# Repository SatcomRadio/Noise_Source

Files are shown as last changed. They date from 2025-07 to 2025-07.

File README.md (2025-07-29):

# Noise source board

This repo consists of a board for making a noise source. 

## Warning! This board is still a work in progress!

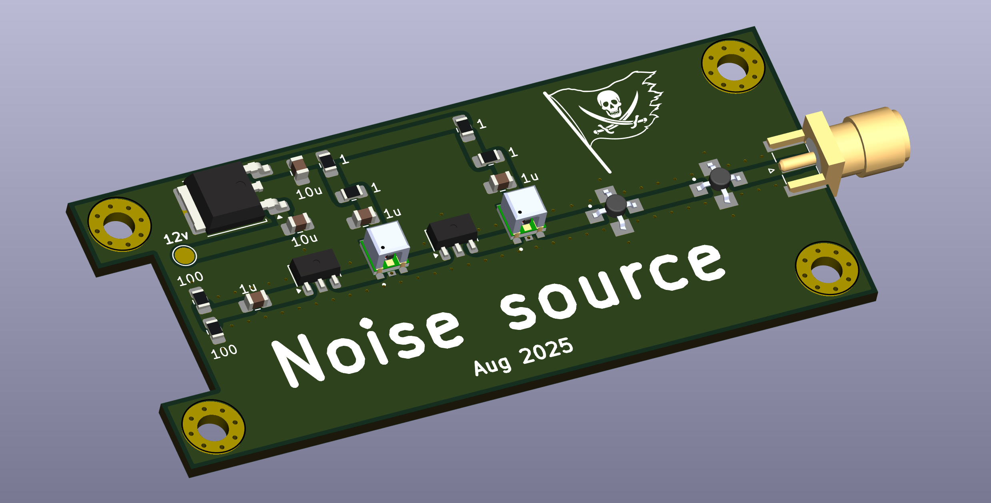
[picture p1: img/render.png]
render


It's based on the one made by [Changpuak](https://www.changpuak.ch/electronics/Noise-Source-with-2xGVA82-15dB.php).

It's adapted to work in a enclosure like [this one](https://www.aliexpress.com/item/1005001849603652.html) of size 92x38x31mm to store it.

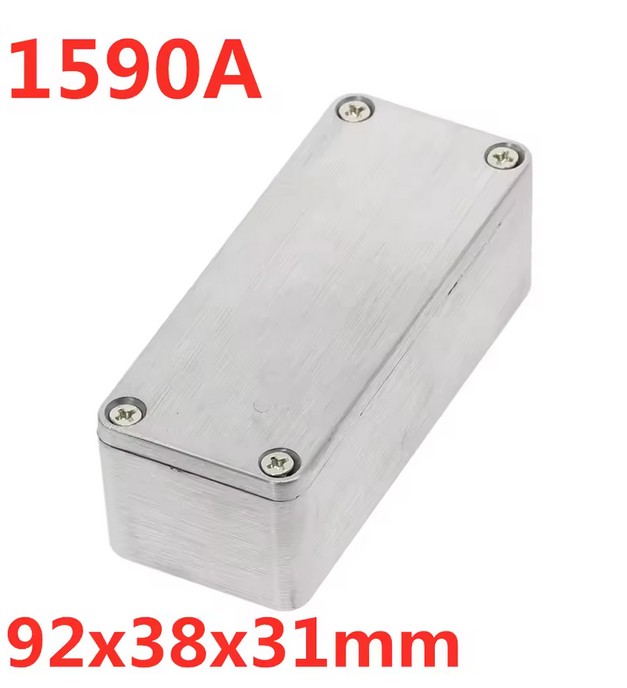
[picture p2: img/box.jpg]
box


------------------------

## Bill of materials

```
4x 0805 1 ohm resistor (https://aliexpress.com/item/1005009264768923.html)
2x 0805 100 ohm resistor (https://aliexpress.com/item/1005009264768923.html)
3x 0805 1uF capacitor (https://aliexpress.com/item/1005005000107445.html)
2x 0805 10uF capacitor (https://aliexpress.com/item/1005005000107445.html)
2x GVA-82+ Mini-Circuits Amplifier (https://aliexpress.com/item/1005008544947091.html)
2x TCBT-14+ Mini-Circuits Bias Tee (https://aliexpress.com/item/1005007678313474.html)
2x PAT-3+ Mini-Circuits 3 dB Attenuator (https://aliexpress.com/item/1005008375039512.html)
1x SMA PCB 1.6mm long connector (https://aliexpress.com/item/1005007424915378.html)
1x 12V barrel jack connector (https://aliexpress.com/item/1005008726787916.html)
1x MC7805CDTG 5v voltage regulator (https://aliexpress.com/item/1005007905517148.html)
1x Storage box (https://www.aliexpress.com/item/1005001849603652.html)
```

------------------------

Schema:

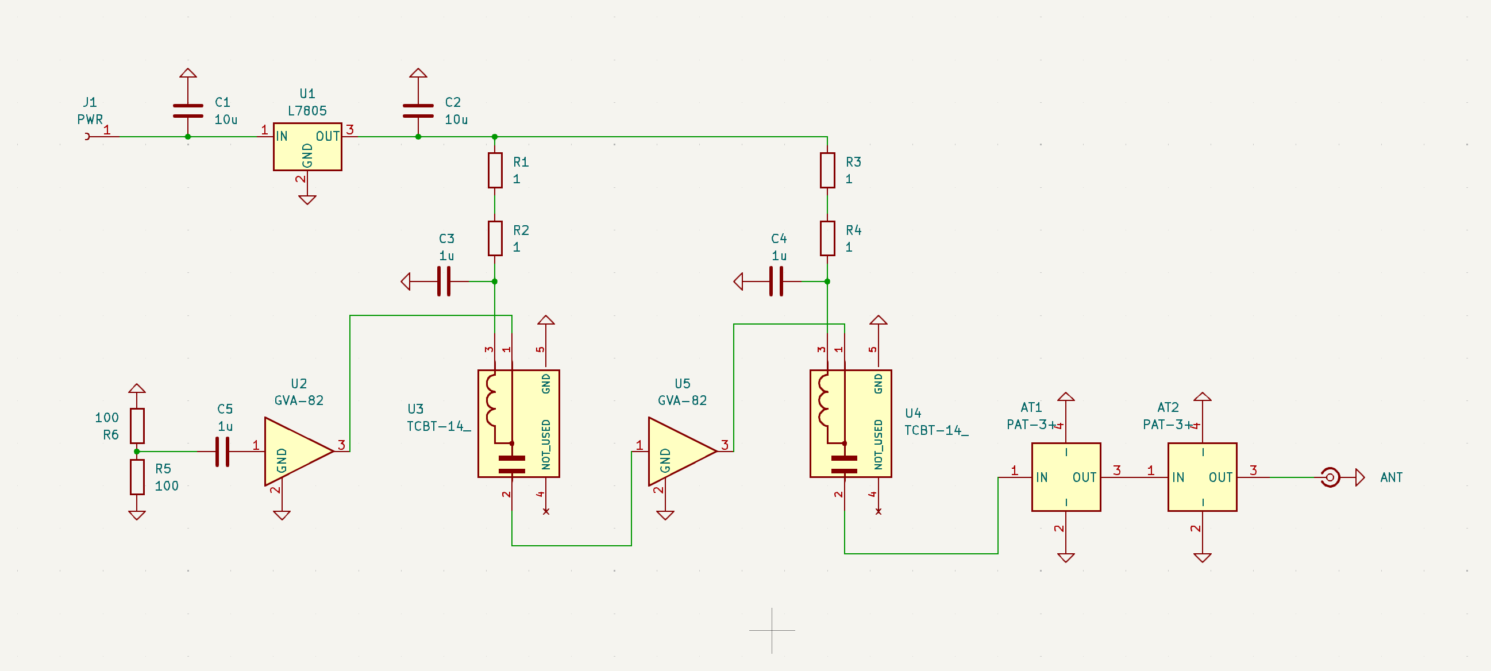
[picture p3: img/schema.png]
schema


------------------------

## Ordering the PCB:

Download the Gerber file from this repo and order it a jlcpcb with the default options.  
The only option I've changed is to remove the manufacture code mark

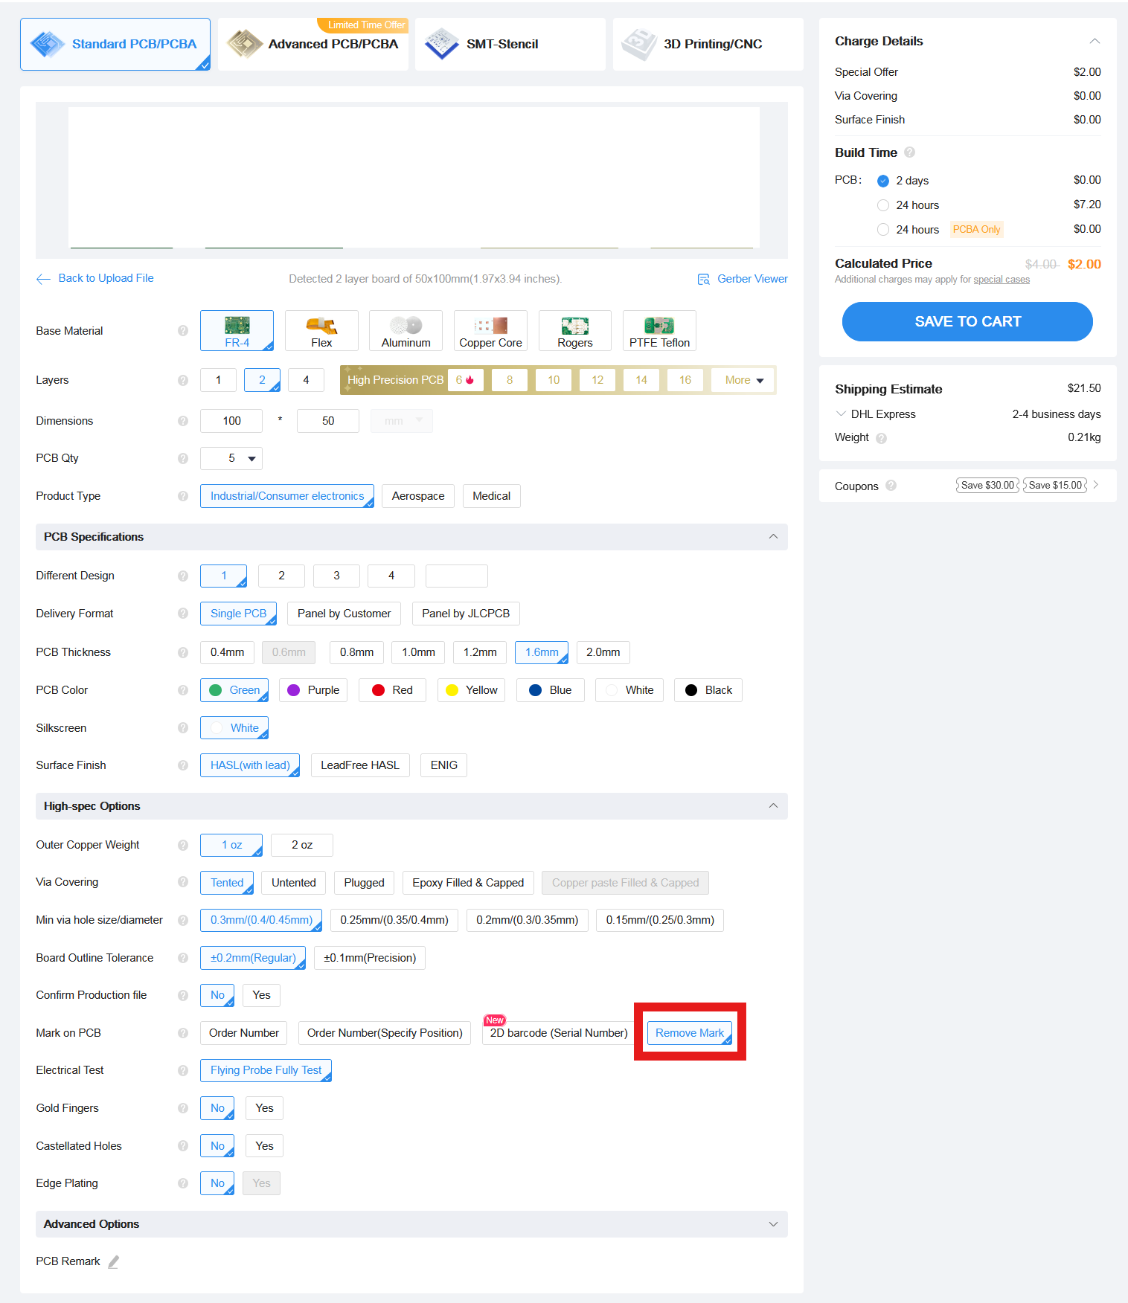
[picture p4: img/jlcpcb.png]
jlcpcb


#### Please make sure to visit the [satcom radio website](https://satcomradio.github.io/) for more information

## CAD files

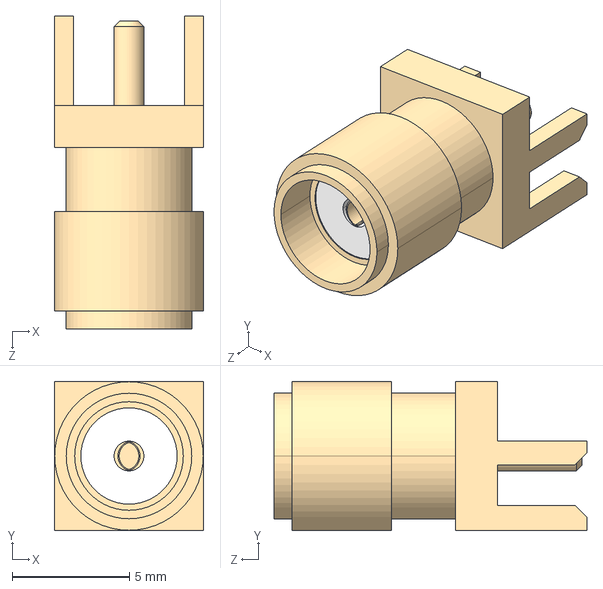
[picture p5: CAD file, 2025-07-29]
Kicad/3d/SMA.step
6.35 x 6.35 x 13.3 mm

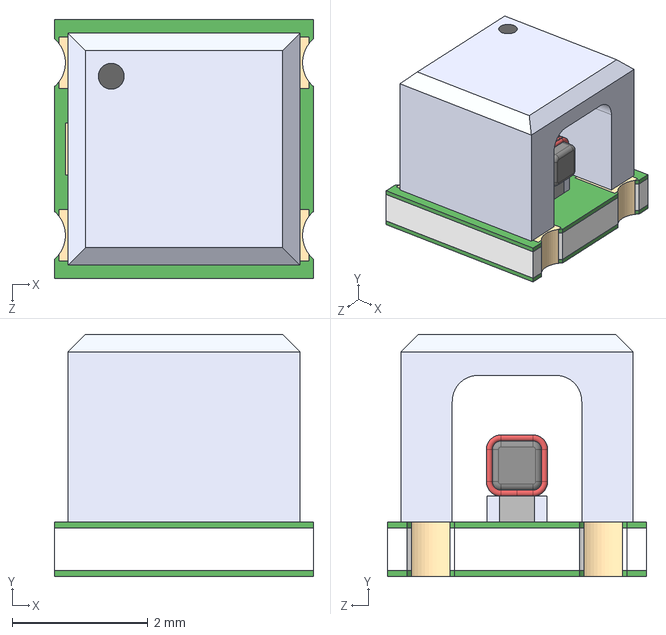
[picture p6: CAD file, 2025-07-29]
Kicad/3d/TCBT-14_.step
3.81 x 3.56 x 3.81 mm

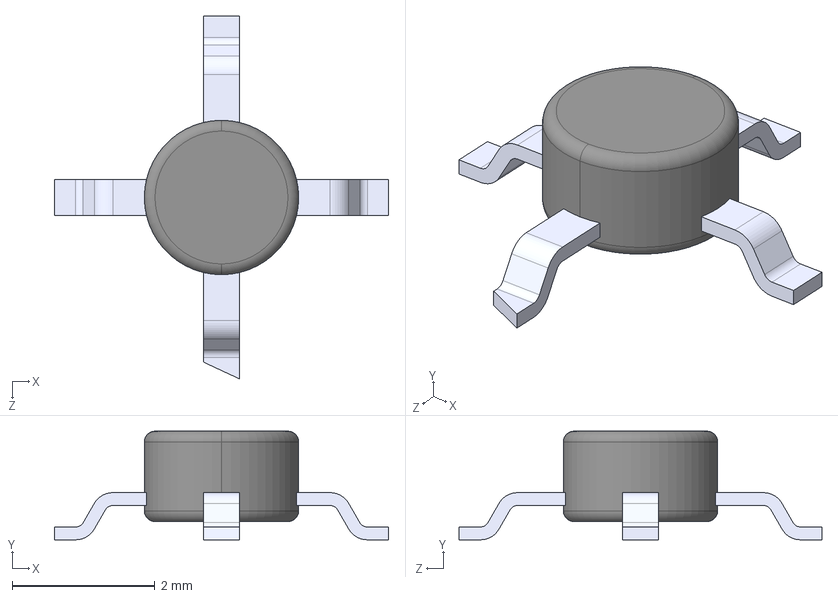
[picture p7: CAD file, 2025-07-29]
Kicad/3d/PAT-3+.STEP
4.68 x 1.52 x 5.08 mm

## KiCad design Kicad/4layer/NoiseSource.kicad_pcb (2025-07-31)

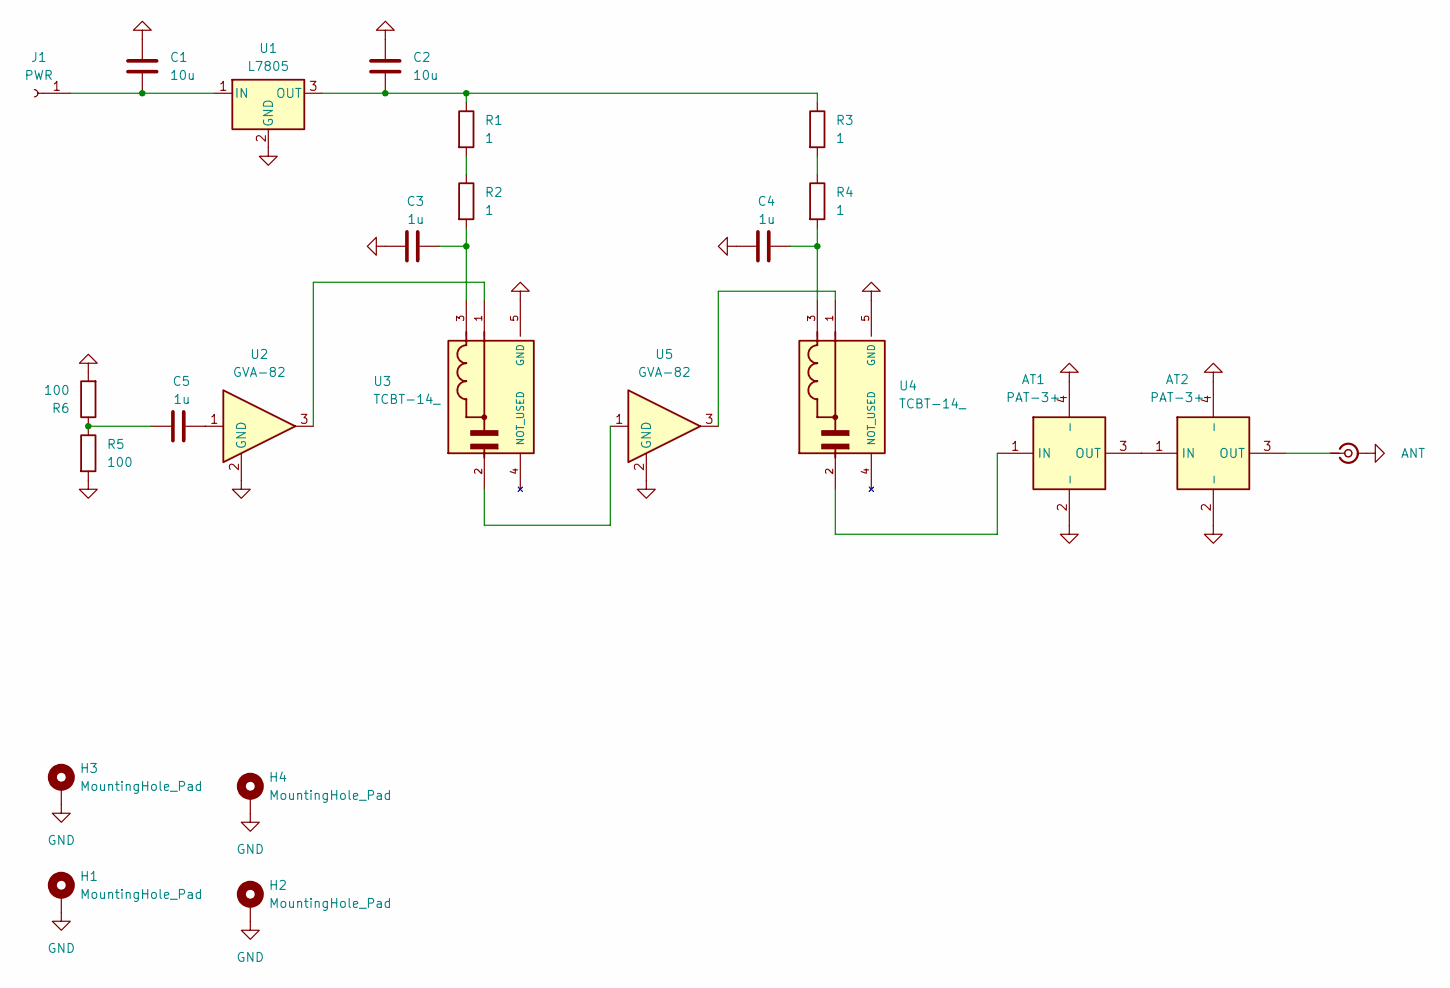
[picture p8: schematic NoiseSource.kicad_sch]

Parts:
AT1, AT2: PAT-3+; PAT3; Mouser Part Number 139-PAT-3+
C1, C2: 10u; C_0805_2012Metric_Pad1.18x1.45mm_HandSolder
C3, C4, C5: 1u; C_0805_2012Metric_Pad1.18x1.45mm_HandSolder
H1, H2, H3, H4: MountingHole_Pad; MountingHole_3.2mm_M3_Pad_Via
J1: PWR; TestPoint_Pad_D2.0mm
J2: ANT; SMA_Edge
R1, R2, R3, R4: 1; R_0805_2012Metric_Pad1.20x1.40mm_HandSolder
R5, R6: 100; R_0805_2012Metric_Pad1.20x1.40mm_HandSolder
U1: L7805; TO-252-2
U2, U5: GVA-82; SOT-89-3_VIAS
U3, U4: TCBT-14_; IC_TCBT-14_; PARTREV C

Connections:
GND: AT1.2 (-), AT1.4 (-), AT2.2 (-), AT2.4 (-), C1.2, C2.2, C3.2, C4.2, H1.1, H2.1, H3.1, H4.1, J2.2 (Ext), R5.2, R6.2, U1.2 (GND), U2.2 (GND), U3.5 (GND), U4.5 (GND), U5.2 (GND)
unnamed: AT1.1 (IN), U4.2
unnamed: AT1.3 (OUT), AT2.1 (IN)
unnamed: AT2.3 (OUT), J2.1 (In)
unnamed: C3.1, R2.2, U3.3
unnamed: C4.1, R4.2, U4.3
unnamed: C5.1, U2.1
unnamed: C5.2, R5.1, R6.1
unnamed: C1.1, J1.1, U1.1 (IN)
unnamed: R1.2, R2.1
unnamed: R3.2, R4.1
unnamed: C2.1, R1.1, R3.1, U1.3 (OUT)
unnamed: U2.3, U3.1
unnamed: U3.2, U5.1
unnamed: U4.1, U5.3

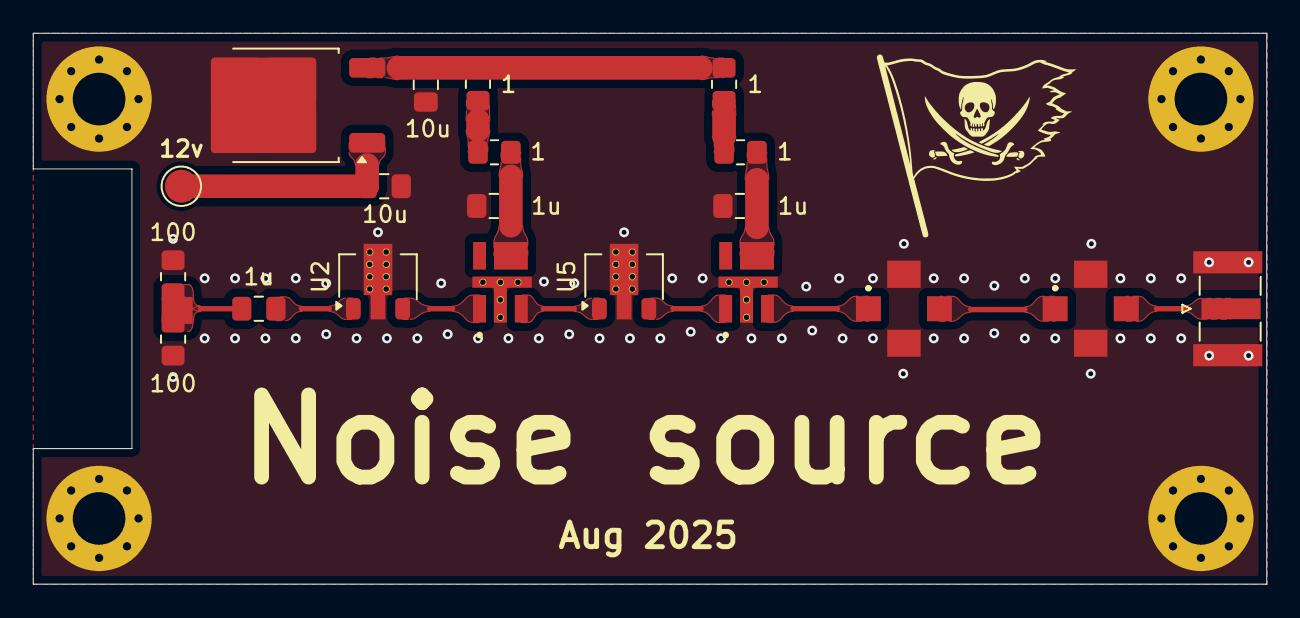
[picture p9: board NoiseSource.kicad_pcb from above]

Board: 4 copper layers, 75.0 x 33.5 mm, 24 parts (0 on the bottom side), 15 nets.

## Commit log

2025-07-29 Initial upload
    [NoiseSource.kicad_pcb, NoiseSource.kicad_sch, PAT-3+.STEP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]
2025-07-29 Update render and footprints
    [NoiseSource.kicad_pcb, SMA.step]
2025-07-31 Added 2 and 4 layer version
    [NoiseSource.kicad_pcb, NoiseSource.kicad_sch]
